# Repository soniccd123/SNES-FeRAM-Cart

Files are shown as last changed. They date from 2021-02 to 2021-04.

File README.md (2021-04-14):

# SNES FeRAM Cart
A Open Hardware SNES Cartridge with save capability

# What is that?
A repro cartridge PCB for SNES and Super Famicom consoles compatible with LoROM and HiROM software and save capability using FeRAM memory. Its a open hardware project and can be modified with no restriction

This project was possible thanks to poorstudenthobbyist (Very nice and informative guides) and whicker (Showed the basics of how to wire a FeRAM to SNES), as well as other members of NESdev forums.

# Why is that?
While there are very nice comercially available repro PCB solutions, these are closed solutions that often doesn't fit the needs of everyone, specially concerning availability of parts, so, making this project open is not only a way to give back to the community that helped me alot, but also to give the ones that need a more versitile way to solve their problems. I know that the way that this PCB was designed may not fit everyone, but i hope that the ability to modify this project as one needs solves this.

I also find the canibalization of original cartridges for making repros, while understandable in many cases, discusting, so, may this project help to curb this practice.

# Features as of now
- Suports SNES and Super Famicom
- ROM Support for up to 4MB
- HiROM and LoROM software (set by jumpers)
- 32KB of FeRAM for saving (256kb)
- No need for backup battery
- Rudimentary ROM bank switch (Permits multiple games on same ROM)
- SuperCIC support
- DOES NOT SUPPORT SPECIAL CHIP GAMES (while i would love to, this is quite away from my capacity as of now)

# Component List:
- 1x FM1808B;
- 1x 27C322 (May use other 27CXX memories with some minor modifications);
- 1x 74HC139 (or LS);
- 1x 4081;
- 1x 4071;
- 2x 74HC245;
- 1x SuperCIC (PIC12F629 model);
- 1x Led (Optional, only used for SuperCIC)
- 4x 1K Resistors (5x if using the LED with the SuperCIC);
- 1x 4 channel DIP Switch;
- 2x 10nF Capacitors;

# Technical details

This project was developed using KiCAD and can be easily modified and studied by using it. Terminals are left in the PCB for all cartridge port connections for testing, but these can easily be removed if wanted.

4081 and 4071 circuitry help to control backup RAM access and also permit FeRAM correctly reading and writing. If

While bank switching is present, its use is not absolutely required for the cart to work. In this case, the resistors are not needed, just short each SW1 channel (as if it were on). 

Also, while save capability is present, it is not required for the cart to work. 4071 and 4081 are still required in these cases

SuperCIC have been tested by other users and works. A SOIC8 footprint will be added aswell in the next commit for more package options.

# How to use

The ROMs to be written to the EPROM need to be headerless and byteswapped, this is very important. The byteswapping need is a artifact of my prototyping process and may be changed in the future.

Be sure that all chips are in the correct orientation. KiCAD stock footprint silkscreen are quite bad at indicating chip's orientation. New clearer silkscreens for the footprints may be added in the future.

ROM type: HiROM and LoROM are selected by shorting the corresponding side of all the jumpers to the center, HiROM ones are annotated with H and LoROM with L.

Bank Switching: The user may write multiple roms to the same EPROM, the DIP switch controls which area of the EPROM is read by the SNES/Super Famicom; The minimum bank size is 256KB. Each of the switches connect a memory address line between the system and the EPROM: when the switch is on, the respective address line is controlled by the SNES; When off, the EPROM adress line is pulled-up and cut from SNES control. the address lines are A20, A19, A18, A17 (considering LSB as A0). To select the desired bank, turn the switches on and off acordingly to the begining address that the ROM occupies in the EPROM.

Examples:

ROM_x begin at 0x100000 -> Switch just A19 off (pull-up);           
ROM_y begin at 0x180000 -> Switch A19 and A18 off;

This technique may not be compatible with save supporting SNES/Super Famicom software.

How to make multirom file: Just use the CMD command "copy /b rom_x.bin + rom_y.bin + rom_z.bin rom_result.bin" to join them to one file. One may join how many ROMs he wants to, just be shure that the result file is smaller than the total size of the EPROM and that the ROMs fit correctly to each desired bank to make software switching possible.

# Disclaimer

I'm not an professional engineer and created this project as a hobby, this said, problems and errors maybe present and in need to be corrected. I'll try you to help the best as I can if any problems arrise but be aware that they may exist.

Happy playing!

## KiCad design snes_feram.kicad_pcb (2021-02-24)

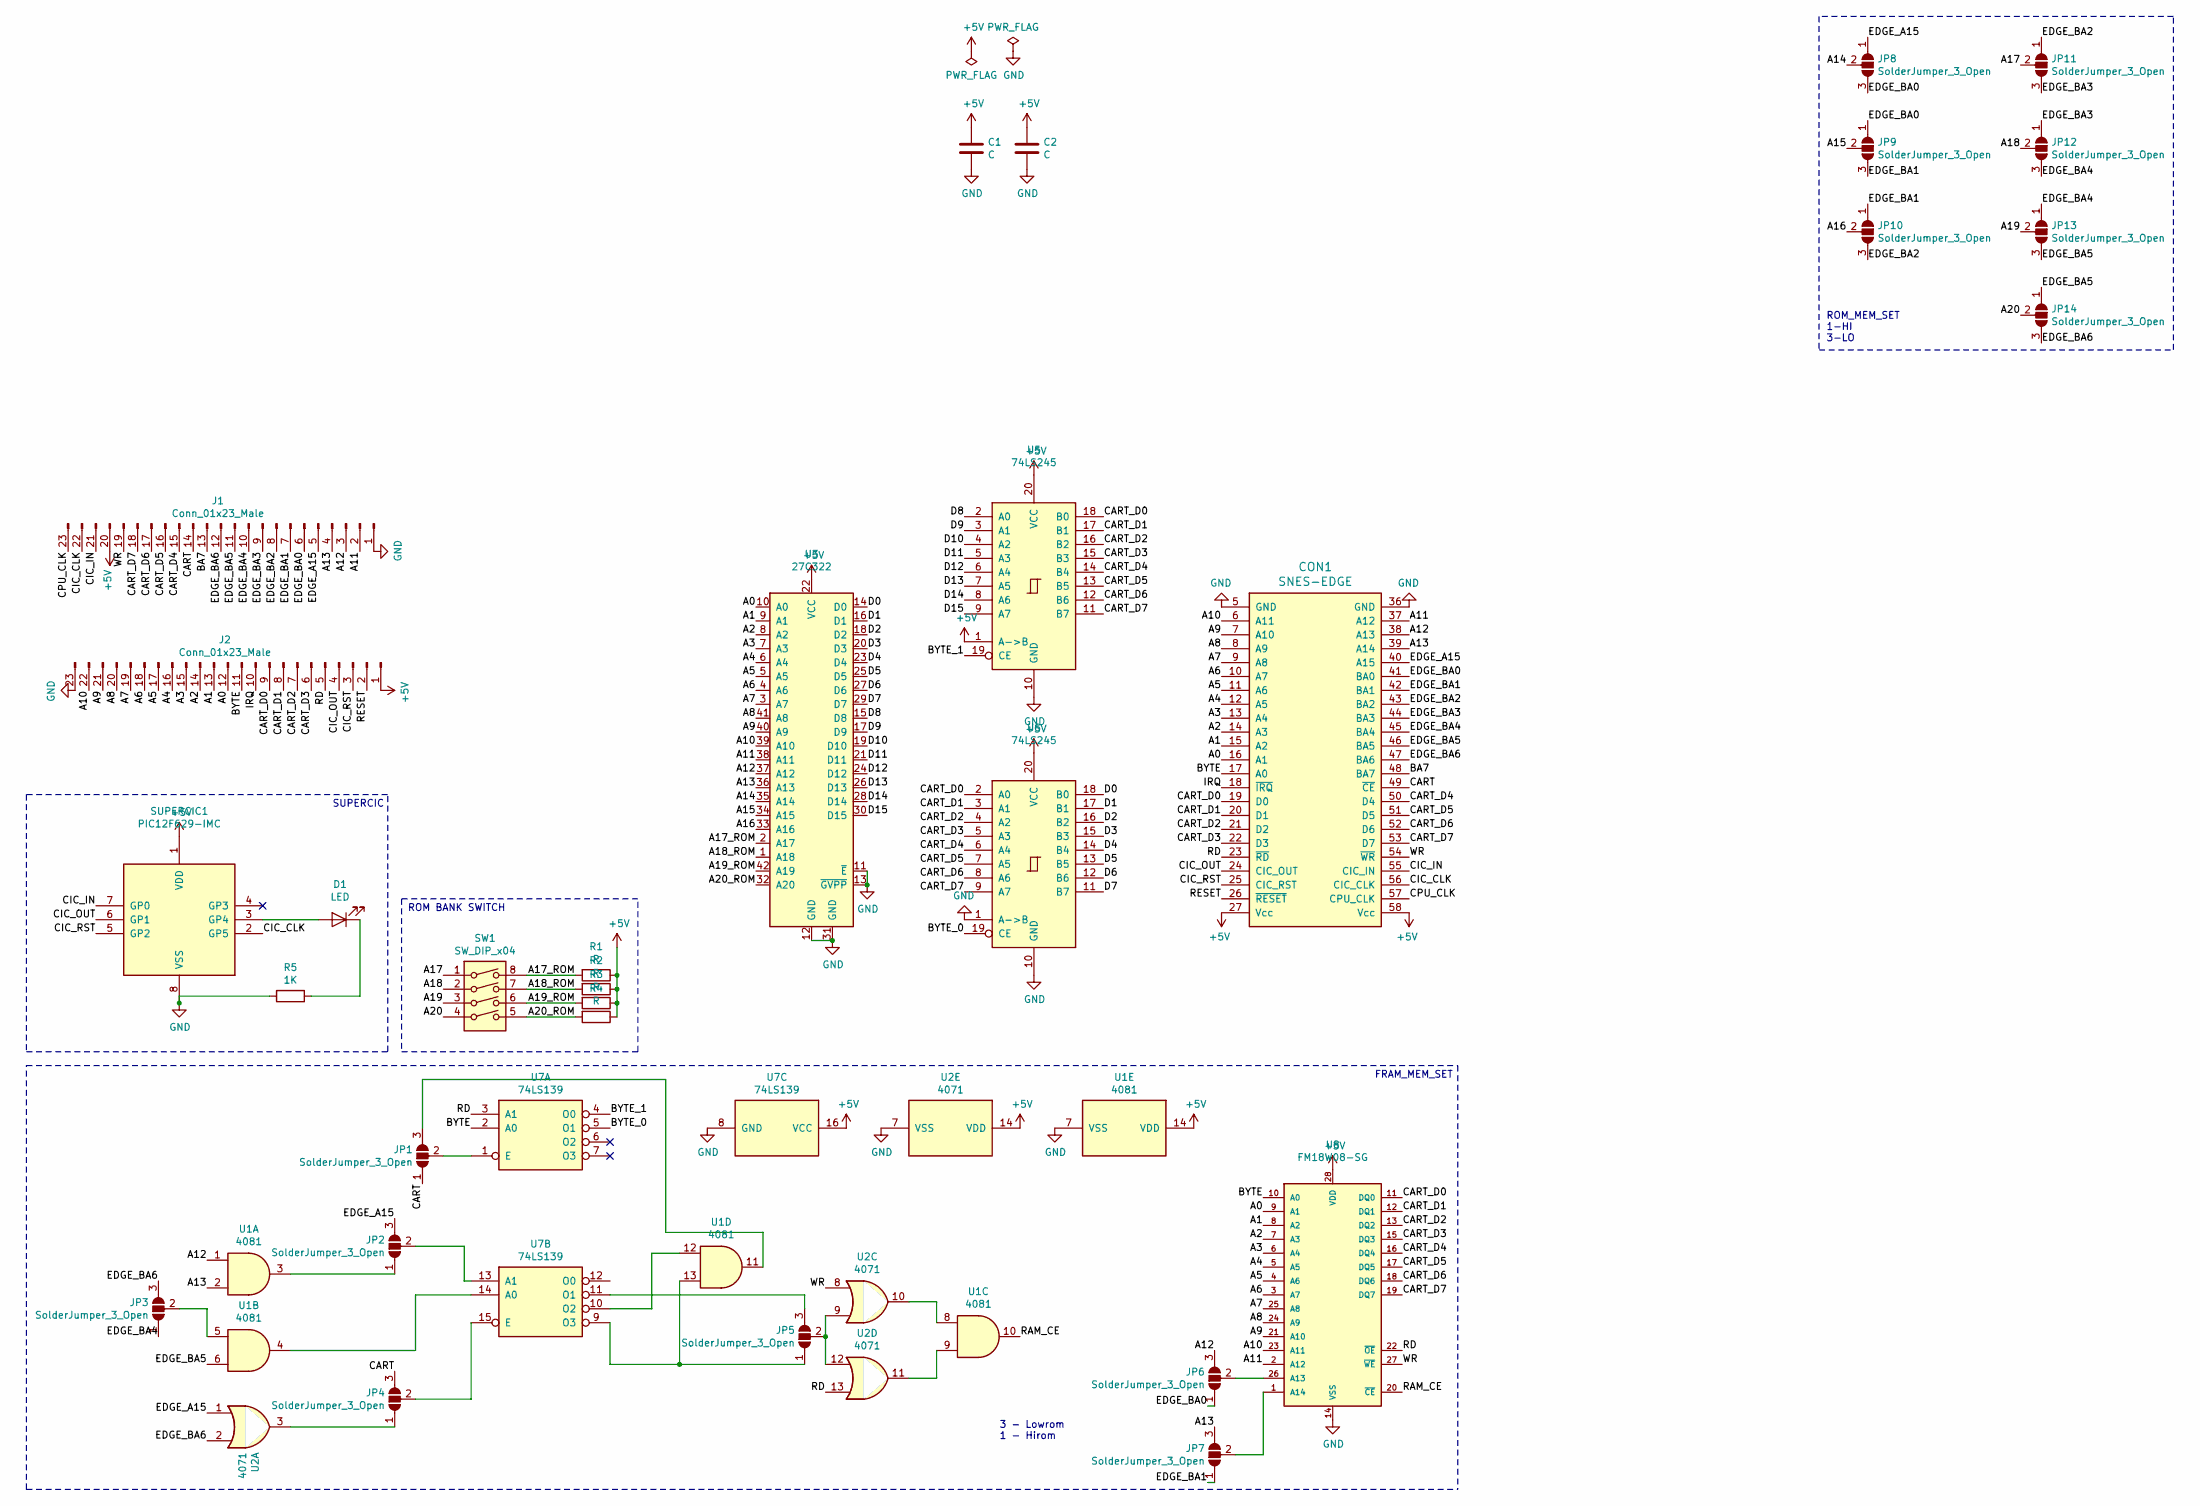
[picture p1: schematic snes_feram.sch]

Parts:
C1, C2: C; C_Disc_D5.0mm_W2.5mm_P2.50mm
CON1: SNES-EDGE; SNES-EDGE-Bigger
D1: LED; LED_D3.0mm
J1, J2: Conn_01x23_Male; PinSocket_1x23_P2.54mm_Vertical
JP1, JP2, JP3, JP4, JP5, JP6, JP7, JP8, JP9, JP10, JP11, JP12, JP13, JP14: SolderJumper_3_Open; SolderJumper-3_P1.3mm_Open_RoundedPad1.0x1.5mm
R1, R2, R3, R4: R; R_Axial_DIN0207_L6.3mm_D2.5mm_P7.62mm_Horizontal
R5: 1K; R_Axial_DIN0207_L6.3mm_D2.5mm_P7.62mm_Horizontal
SUPERCIC1: PIC12F629-IMC; DIP-8_W7.62mm
SW1: SW_DIP_x04; SW_DIP_SPSTx04_Slide_9.78x12.34mm_W7.62mm_P2.54mm
U1: 4081; SOIC-14_3.9x8.7mm_P1.27mm
U2: 4071; SOIC-14_3.9x8.7mm_P1.27mm
U3: 27C322; DIP-42_W15.24mm
U5, U6: 74LS245; SOIC-20W_7.5x12.8mm_P1.27mm
U7: 74LS139; SOIC-16_3.9x9.9mm_P1.27mm
U8: FM18W08-SG; SOIC-28W_7.5x17.9mm_P1.27mm

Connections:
+5V: C1.1, C2.1, CON1.27 (Vcc), CON1.58 (Vcc), J1.20, J2.1, R1.1, R2.1, R3.1, R4.1, SUPERCIC1.1 (VDD), U1.14 (VDD), U2.14 (VDD), U3.22 (VCC), U5.1 (A->B), U5.20 (VCC), U6.20 (VCC), U7.16 (VCC), U8.28 (VDD); also elsewhere on the board
/A0: CON1.16 (A1), J2.12, U3.10 (A0), U8.9 (A1)
/A1: CON1.15 (A2), J2.13, U3.9 (A1), U8.8 (A2)
/A2: CON1.14 (A3), J2.14, U3.8 (A2), U8.7 (A3)
/A3: CON1.13 (A4), J2.15, U3.7 (A3), U8.6 (A4)
/A4: CON1.12 (A5), J2.16, U3.6 (A4), U8.5 (A5)
/A5: CON1.11 (A6), J2.17, U3.5 (A5), U8.4 (A6)
/A6: CON1.10 (A7), J2.18, U3.4 (A6), U8.3 (A7)
/A7: CON1.9 (A8), J2.19, U3.3 (A7), U8.25 (A8)
/A8: CON1.8 (A9), J2.20, U3.41 (A8), U8.24 (A9)
/A9: CON1.7 (A10), J2.21, U3.40 (A9), U8.21 (A10)
/A10: CON1.6 (A11), J2.22, U3.39 (A10), U8.23 (A11)
/A11: CON1.37 (A12), J1.2, U3.38 (A11), U8.2 (A12)
/A12: CON1.38 (A13), J1.3, JP6.3 (B), U1.1, U3.37 (A12)
/A13: CON1.39 (A14), J1.4, JP7.3 (B), U1.2, U3.36 (A13)
/A14: JP8.2 (C), U3.35 (A14)
/A15: JP9.2 (C), U3.34 (A15)
/A16: JP10.2 (C), U3.33 (A16)
/A17: JP11.2 (C), SW1.1
/A17_ROM: R1.2, SW1.8, U3.2 (A17)
/A18: JP12.2 (C), SW1.2
/A18_ROM: R2.2, SW1.7, U3.1 (A18)
/A19: JP13.2 (C), SW1.3
/A19_ROM: R3.2, SW1.6, U3.42 (A19)
/A20: JP14.2 (C), SW1.4
/A20_ROM: R4.2, SW1.5, U3.32 (A20)
/BA7: CON1.48 (BA7), J1.13
/BYTE: CON1.17 (A0), J2.11, U7.2 (A0), U8.10 (A0)
/BYTE_0: U6.19 (CE), U7.5 (O1)
/BYTE_1: U5.19 (CE), U7.4 (O0)
/CART: CON1.49 (~CE), J1.14, JP1.1 (A), JP4.3 (B)
/CART_D0: CON1.19 (D0), J2.9, U5.18 (B0), U6.2 (A0), U8.11 (DQ0)
/CART_D1: CON1.20 (D1), J2.8, U5.17 (B1), U6.3 (A1), U8.12 (DQ1)
/CART_D2: CON1.21 (D2), J2.7, U5.16 (B2), U6.4 (A2), U8.13 (DQ2)
/CART_D3: CON1.22 (D3), J2.6, U5.15 (B3), U6.5 (A3), U8.15 (DQ3)
/CART_D4: CON1.50 (D4), J1.15, U5.14 (B4), U6.6 (A4), U8.16 (DQ4)
/CART_D5: CON1.51 (D5), J1.16, U5.13 (B5), U6.7 (A5), U8.17 (DQ5)
/CART_D6: CON1.52 (D6), J1.17, U5.12 (B6), U6.8 (A6), U8.18 (DQ6)
/CART_D7: CON1.53 (D7), J1.18, U5.11 (B7), U6.9 (A7), U8.19 (DQ7)
/CIC_CLK: CON1.56 (CIC_CLK), J1.22, SUPERCIC1.2 (GP5); also elsewhere on the board
/CIC_IN: CON1.55 (CIC_IN), J1.21, SUPERCIC1.7 (GP0); also elsewhere on the board
/CIC_OUT: CON1.24 (CIC_OUT), J2.4, SUPERCIC1.6 (GP1); also elsewhere on the board
/CIC_RST: CON1.25 (CIC_RST), J2.3, SUPERCIC1.5 (GP2); also elsewhere on the board
/CPU_CLK: CON1.57 (CPU_CLK), J1.23
/D0: U3.14 (D0), U6.18 (B0)
/D1: U3.16 (D1), U6.17 (B1)
/D2: U3.18 (D2), U6.16 (B2)
/D3: U3.20 (D3), U6.15 (B3)
/D4: U3.23 (D4), U6.14 (B4)
/D5: U3.25 (D5), U6.13 (B5)
/D6: U3.27 (D6), U6.12 (B6)
/D7: U3.29 (D7), U6.11 (B7)
/D8: U3.15 (D8), U5.2 (A0)
/D9: U3.17 (D9), U5.3 (A1)
/D10: U3.19 (D10), U5.4 (A2)
/D11: U3.21 (D11), U5.5 (A3)
/D12: U3.24 (D12), U5.6 (A4)
/D13: U3.26 (D13), U5.7 (A5)
/D14: U3.28 (D14), U5.8 (A6)
/D15: U3.30 (D15), U5.9 (A7)
/EDGE_A15: CON1.40 (A15), J1.5, JP2.3 (B), JP8.1 (A), U2.1
/EDGE_BA0: CON1.41 (BA0), J1.6, JP6.1 (A), JP8.3 (B), JP9.1 (A)
/EDGE_BA1: CON1.42 (BA1), J1.7, JP7.1 (A), JP9.3 (B), JP10.1 (A)
/EDGE_BA2: CON1.43 (BA2), J1.8, JP10.3 (B), JP11.1 (A)
/EDGE_BA3: CON1.44 (BA3), J1.9, JP11.3 (B), JP12.1 (A)
/EDGE_BA4: CON1.45 (BA4), J1.10, JP3.1 (A), JP12.3 (B), JP13.1 (A)
/EDGE_BA5: CON1.46 (BA5), J1.11, JP13.3 (B), JP14.1 (A), U1.6
/EDGE_BA6: CON1.47 (BA6), J1.12, JP3.3 (B), JP14.3 (B), U2.2
/IRQ: CON1.18 (~IRQ), J2.10
/RAM_CE: U1.10, U8.20 (~CE~)
/RD: CON1.23 (~RD), J2.5, U2.13, U7.3 (A1), U8.22 (~OE~)
/RESET: CON1.26 (~RESET), J2.2
/WR: CON1.54 (~WR), J1.19, U2.8, U8.27 (~WE~)
GND: C1.2, C2.2, CON1.5 (GND), CON1.36 (GND), J1.1, J2.23, R5.2, SUPERCIC1.8 (VSS), U1.7 (VSS), U2.7 (VSS), U3.11 (~E), U3.12 (GND), U3.13 (~GVPP), U3.31 (GND), U5.10 (GND), U6.1 (A->B), U6.10 (GND), U7.8 (GND), U8.14 (VSS); also elsewhere on the board
unnamed: D1.1 (K), R5.1
unnamed 75: D1.2 (A), SUPERCIC1.3 (GP4); also elsewhere on the board
unnamed: JP1.2 (C), U7.1 (E)
unnamed: JP1.3 (B), U1.11
unnamed: JP2.1 (A), U1.3
unnamed: JP2.2 (C), U7.13 (A1)
unnamed: JP3.2 (C), U1.5
unnamed: JP4.1 (A), U2.3
unnamed: JP4.2 (C), U7.15 (E)
unnamed: JP5.1 (A), U1.13, U7.9 (O3)
unnamed: JP5.2 (C), U2.9, U2.12
unnamed: JP5.3 (B), U7.11 (O1)
unnamed: JP6.2 (C), U8.26 (A13)
unnamed: JP7.2 (C), U8.1 (A14)
unnamed: U1.4, U7.14 (A0)
unnamed: U1.8, U2.10
unnamed: U1.9, U2.11
unnamed: U1.12, U7.10 (O2)

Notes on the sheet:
3 - Lowrom 1 - Hirom
FRAM_MEM_SET
ROM_MEM_SET 1-HI 3-LO
SUPERCIC
ROM BANK SWITCH

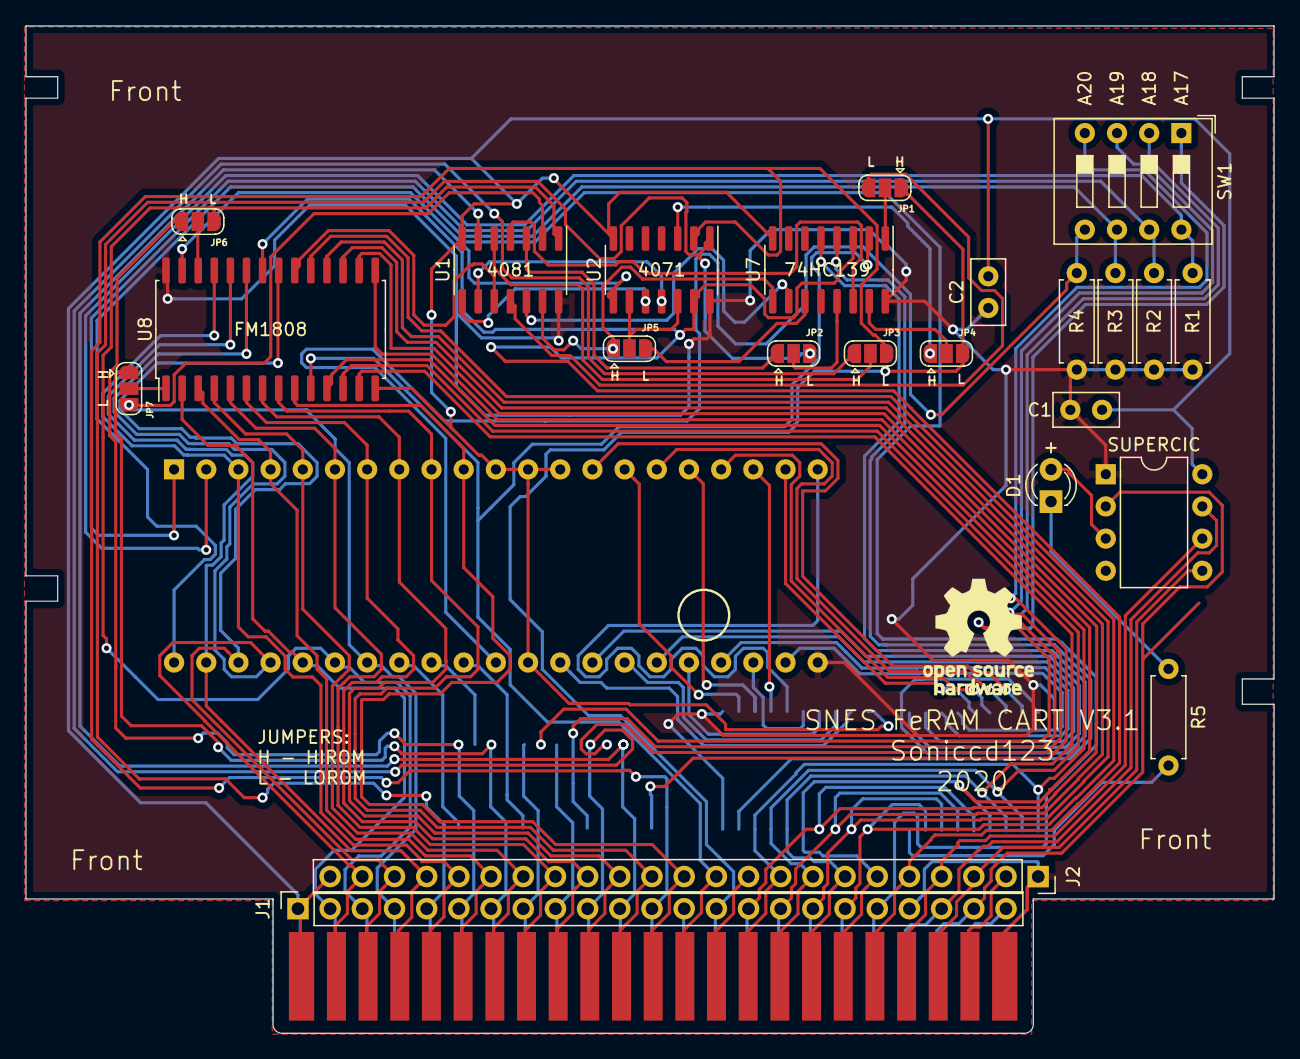
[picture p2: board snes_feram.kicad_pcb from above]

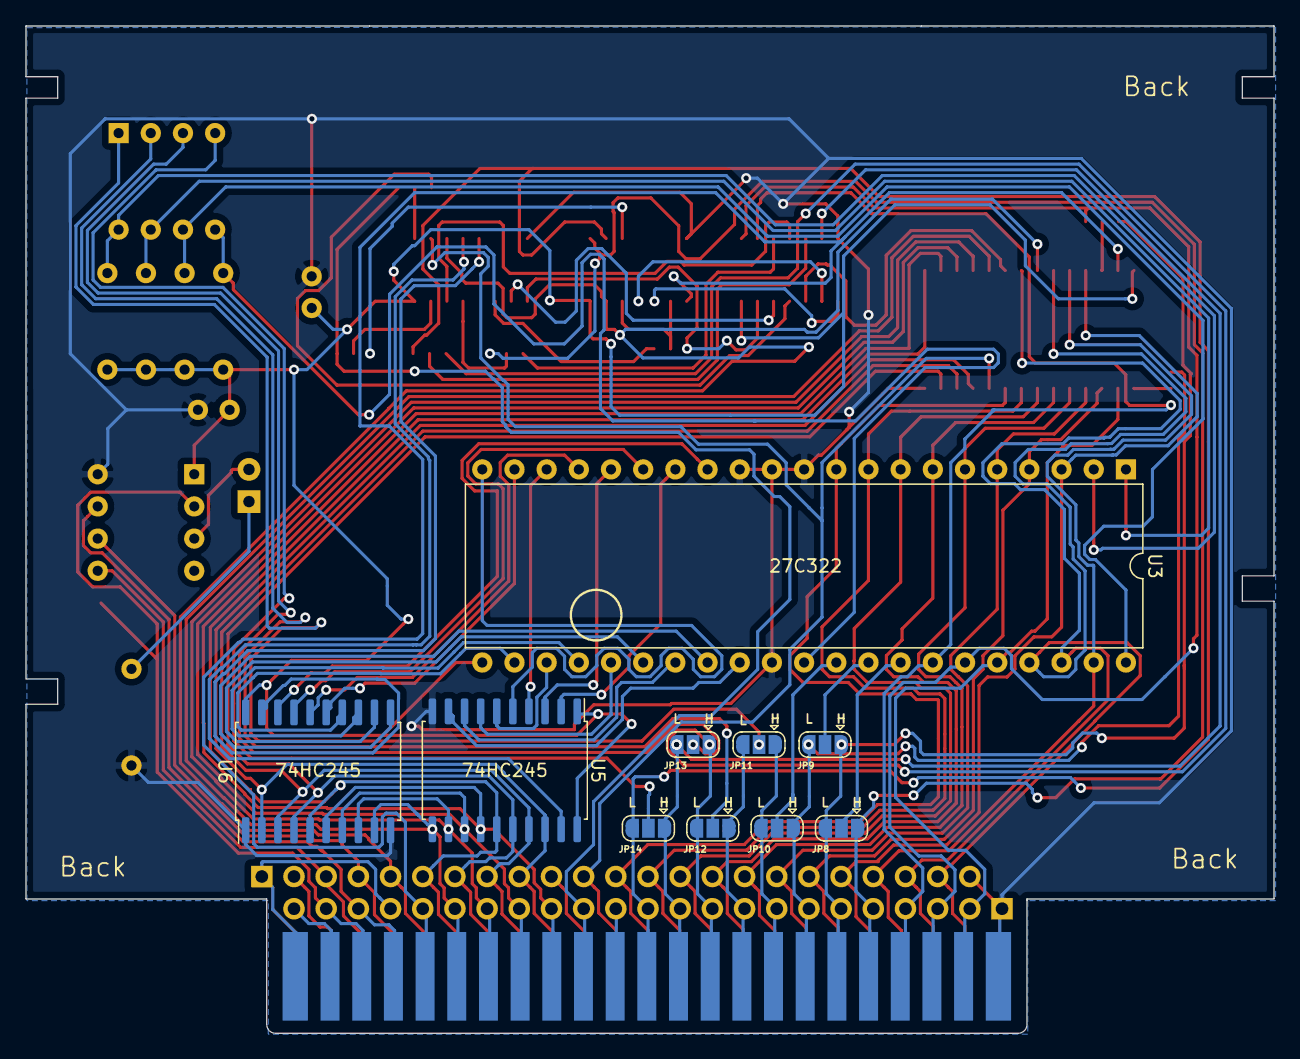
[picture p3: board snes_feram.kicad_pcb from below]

Board: 2 copper layers, 98.5 x 79.5 mm, 34 parts (10 on the bottom side), 92 nets.

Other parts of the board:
SUPERCIC: PIC12F629-IMC; DIP-8_W7.62mm

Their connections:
+5V: SUPERCIC.1; also elsewhere on the board
/CIC_CLK: SUPERCIC.2; also elsewhere on the board
/CIC_IN: SUPERCIC.7; also elsewhere on the board
/CIC_OUT: SUPERCIC.6; also elsewhere on the board
/CIC_RST: SUPERCIC.5; also elsewhere on the board
GND: SUPERCIC.8; also elsewhere on the board
unnamed 75: SUPERCIC.3; also elsewhere on the board

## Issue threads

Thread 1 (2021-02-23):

U5 has no +5V power connected to pin 20

pi1541, 2021-02-23:
Have you tried your Kicad PCB?
U5 has no +5 power connected to pin 20.
Perhaps the CMOS just works?

soniccd123, 2021-03-12:
Hey, sorry, just seen this now. It is already fixed, I forgot this trace somehow when I changed the EPROM from the front to the backside of the PCB (to fit the case correctly). Thanks for pointing out.

Closed 2021-03-12.

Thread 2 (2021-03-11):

I have made pcb in january

Pixotero, 2021-03-11:
What problems can I have? I have pcb model january but if the pin 20 is wrong, can I solution this problem? Is a important problem? Sorry for my english, I hope you understand my cuestion. Thanks

soniccd123, 2021-03-12:
Hey, it was my fault, I forgot to connect the pin 20 when I made some changes, but it is very easy to fix, just connect pin 20 to 5v using a small jumper wire (U5 pin 1 is a good candidate). It is already fixed since last commit, but for those who had built PCBs before, this should fix it. The cart will probably not work if this is not done.

When you build your PCB, just confirm to me that it works so I can close the Issue :)

Pixotero, 2021-03-15:
I have built PCB before, I am going apply the solution that you have to proposed to me. anyway, I am studying how to make the cartridges because I am a beginner. I have the list of components and the pcb, but I need to know which ones to use and how, I know that I need to program 27c322 and pic12f629, but I don't know which components to solder. Thanks for your solution. I will write my progress if you want, thanks again

Pixotero, 2022-10-29:
I have abandoned the project for months because I have not been able to program 27c322 with the willem programmer. I would like to resume it, I don't know if you could help me with that, thanks

soniccd123, 2022-10-29:
Hi friend, unfortunately, I program my EPROMs with a custom programmer that I built, but any programmer capable of writting 27c322 should work. I don't know how can I help you with that

alexwinger, 2023-09-17:
I built a pcb the cart is working without any modification. So i think you can close the issue

SiscuPrats, 2024-01-09:
I would like to know if in the end the project and the board works correctly. Has anyone finally tested the prototype and programmed any game?

alexwinger, 2024-03-11:
> I would like to know if in the end the project and the board works correctly. Has anyone finally tested the prototype and programmed any game?

It worked for me, but you have to swap the bytes before flashing (Odd <==> Even)

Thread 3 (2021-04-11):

Does this design work?

pi1541, 2021-04-11:
Hi.
I have made a number of these but I can't get any of them to work.
I am trying V3.1.
I am trying many HiROM images and have all the jumpers set to H.
I have all the dip switches turned on.

I have a wire jumper from pin 1 to pin 20 of U5 to fix the missing 5v connection to pin 20 of U5. Is this correct?
Can I confirm that the silk screen for U1, U2 and U7 is the wrong way around and all of these chips have their pin 1 closest to the left side of the board where the dip switches are? That is opposite to the U labels on the silk screen.
Are any other markings on the silk screen wrong?

When you say "byte swapped" do you mean byte swapped using a tool like Wasabi or do you mean 16bit endian byte swapped? I have tried both and neither worked.

I know that my CIC chip works as it works successfully in other designs.

I don't know what to try next. All attempt give a black screen.

I have built other peoples designs without issue but can't seem get this one to work.
Any help or advice would be greatly appreciated.
I want to use this design as it has many desirable features and looks like it is the best one yet.

Oh, and another little thing. In the README.dm in the paragraph about bank switching it talks about the Sega Genesis and not the SNES.

Thanks.

soniccd123, 2021-04-14:
Hello!

Yes, the design work, me and a bunch of other users at NesDev forums have tested it and made repros successfully.

The wire from pin 1 to 20 on U5 is correct and works. Also, I can confirm that U1, U2 and U7 have indeed pin 1 in direction of the DIP switches. Thanks for pointing out, may change the silkscreen in next commit.

Be aware that U5 and U6 are both in oposite directions from each other, in this case, U5 pin 1 is in direction of the back side jumpers.

To see the correct orientation of the chips in KiCAD, take a look at the F.Fab and B.Fab layers, they show the pin 1 of each chip explicitly. KiCAD's silkscreen markings are terrible, in the next commit, I will add very explicit marks for pin 1 of each chip, as this is causing problems even to me lol.

With byteswapped I mean that odd and even bytes must be swapped, if bytes 0, 1, 2 and 3 in the file are A, B, C and D you must write them in the EPROM as B, A, D, C. Each word must be swapped, so it is 16bit endianness, not the Wasabi swap (that changes addresses to fit diferent EPROMs pinouts).

Thanks for pointing out about the Genesis mistake, I use the exact same bank switching method in this and my Genesis Repro, so must have forgot to change the names lol.

Hope this helps!

pi1541, 2021-04-16:
Thanks, I will keep debugging my soldering work.

pi1541, 2021-06-13:
I tried it on another SNES and it worked perfectly. Thanks.

Closed 2021-06-13.

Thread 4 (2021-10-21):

FM16W08-SG (64Kbit)

StanMOI, 2021-10-21:
Hi sonnic,

I would like to use **FM16W08-SG** (64Kbit).
I see that only **pin 1** and **pin 26** are not used with FM16W08.
Should I do something else with FM16W08 when its for Hirom or Lorom use?
Will adress pins changes for **FM16W08-SG** if I will use it for Hirom or Lorom game? (Like in the case of FM18W08).
Or all I need to do Is just tied all pins to respective address names, except pin 1 and 26 (that need to be tied to GND).
Thank you for help.
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

soniccd123, 2021-11-01:
Hi friend, from what I remember you can just solder the FM1608 directly in the FM1808 footprint without modifications, the are pin compatible. Also, I may be wrong, but I think you won't need the connect the NC pins to GND...

The HiROM and LoROM connection schemes access the cartridge in diferently sized banks (32kbit and 64kbit), they also have the save memory mapped in diferent locations in the SNES address space, thats why they're wired diferently.

May I ask why are you interested in using diferent sized FeRAMs like 16kbit? If it is because of the anti-copier/flashcart checks that some games like DKC2 do, you can just crack these games before writing the EEPROM with UCON64 and use bigger save memory sizes

StanMOI, 2021-11-01:
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

Hi sonnic,
Thank you for your answer.
Yes,
I know that some games that DLC2 do check anti-copier/flashcart and it’s can be cracked with UCON64,
 but I still would like to have that option on my future PCB that you can to choose what feram size i will solder on it (like fm1608 with 64Kbit…) etc.
Why not?
And maybe also, just to avoid to use ucon64 or other applications when it can be avoided.
:)

soniccd123, 2022-01-24:
Hello friend,

I'm sorry that it to took so long to reply, the last semester was quite hard at college and i didn't had the time to look into my project for the last few months. Hopefully i'll get more time this year.

Well, using the correct sized FeRAM is perfectly possible, just solder it as shown in the chip pinout and it should work, the higher addresses will simply not be connected. Yet I must warn you that I have not tested this, if you try it, please be sure to report any trouble or success here, it will be very much apreciated! I won't test because while I have quite a large collection of FM1808 chips laying arround, I don't have any FM16W08 to test it. About the NC to GND situation, I'm not sure, it really depends if the pins are really internally connected to the silicon, I can't really answer that about the FM16W08

About the mapping, it does not depend on the game size, HiROM and LoROM will map the save to their respective address in the address space. Size can influence the complexity of the save RAM mappers, as smaller games tends to not try to read higher addresses that may conflict with the save RAM.

We can keep the same pins for the FeRAM footprint because as the jumpers are shorted for LoROM or HiROM in my board, the important pins that maps the save RAM for each one are changed. Thats why this project PCB has so much jumpers.

When I was designing this project, The main resource I used for understanding the memory mapping was poorstudenthobbys blog (today know as Mouse Bite Labs), It has a lot of information explaining how to mapping words. Also, the NESdev forums had a lot of resources, unfortunately, it seems to be offline, I hope that it comes back one day or, at least, a backup of it remains

Don't be sorry! I'm glad that you're interested in the project, I hope to have helped with your questions. If you have anymore questions or need more indepth answers, don't be afraid to ask!

StanMOI, 2022-02-01:
Thank you for answer soniccd123.

I have some more questions for you.

- 74LS245 (Octal Bus Transceiver): For what function do you use it on your board?
Others board using "multiplexers" like 74*257 to convert data from EPROM (16bit) to SNES system (8bit).
I see that you don't have any Multiplexer. Why?

- I see on your schema "**BYTE_0**" and "**BYTE_1**" between decoder 74LS139 (pins 4 and 5) and 74LS245 (pin19 CE)
and also  "**BYTE**" between SNES-EDGE pin17 (A0) and FM18W08 pin10 (A0).
Why?
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

- I would like to try your schema for using with Flash chip like MX29LV320 (8 bit) instead of EPROM 32MBIT (16bit).
If I setup Flash chip to 8bit, so I don't need any multiplexer.
With Flash chip, do I still have to use  2x 74LS245 ?
Do i have to keep all pinouts with name "BYTE" (BYTE, BYTE_0, BYTE_1).
Do you think it can works?
Or schema have to be changed for flash chip?
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

And just to let you know, NESdev forum work again ;)

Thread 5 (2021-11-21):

Problem on the SRAM enable logic of the 4081-U1B part

SONIC3D, 2021-11-21:
Thanks for your nice project. I'm reading your schematic yesterday, with an SNES cart mapping doc on "[http://gatchan.net/uploads/Consoles/SNES/Flashcard/SNES_MemMap.txt](http://gatchan.net/uploads/Consoles/SNES/Flashcard/SNES_MemMap.txt)"
and "[https://wiki.superfamicom.org/schematics-ports-and-pinouts](https://wiki.superfamicom.org/schematics-ports-and-pinouts)"

I found the SRAM mapping is different from what the doc described. So I create this issue to request your help on confirming if it's intended or just small fault on drawing schematic.

(All address pin name below is referencing to CartSlot pin name, not the NET name in your KiCAD project.)

### HiROM mode

With this doc the SRAM enable logic equation in "HiROM mode" is:

```
!SRAM_CE = (!A15 & BA5 & A14 & A13) & (!nCART & nRESET)
or
!SRAM_CE = (!BA6 & BA5 & A14 & A13) & (!nCART & nRESET)
```
and the SRAM should be mapped to segment $20-$3F and $A0-$BF.

When JP1-JP5 shorted with pin1-pin2.(Enable HiROM mode)
Focusing on the part (!A15 & BA5 & A14 & A13) or (!BA6 & BA5 & A14 & A13):
* 4071-U2A part is corresponding to (!A15 and !BA6) which is OK for general adaption.
* 4081-U1A part is corresponding to (A14 & A13).
* But for 4081-U1B part, the equation in your schematic is (BA4 & BA5). Which contains an additional BA4.
This makes the SRAM be mapped to segment $30-$3F and $B0-$BF. Which is different from the known doc.

### LoROM mode

With this doc the SRAM enable logic equation in "LoROM mode" is:
```
!SRAM_CE = (Vcc & BA5 & BA4 & !A15) & (!nCART & nRESET)
or
!SRAM_CE = (BA6 & BA5 & BA4 & !A15) & (!nCART & nRESET)
```
and the SRAM should be mapped to segment $70-$7D and $F0-$FF.

When JP1-JP5 shorted with pin3-pin2.(Enable LoROM mode)
Focusing on the part (Vcc & BA5 & BA4 & !A15) or (BA6 & BA5 & BA4 & !A15):
* JP4 connected to /CART filtered segment $7E-$7F. That's ok.
* 4081-U1A part is corresponding to (!A15). That's ok.
* But for 4081-U1B part the equation in your schematic is (BA6 & BA5). So the BA4 is missed in expression.
This makes the SRAM be mapped to segment $60-$7D and $E0-$FF. Which is different from the known doc.

### My modification
If the above problem is indeed mistake in drawing. I think the modification can be like below.

The solution A uses the expression (BA6 & BA5 & BA4 & !A15) in LoROM mode. It requires an additional AND gate. So I added an 4081. Or it can be achieved with an 3-input AND gate with BA4 BA5 BA6 as input.
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

The solution A uses the expression (Vcc & BA5 & BA4 & !A15), so the Vcc can be skipped in AND. The additional AND gate component can be saved. The jumper can also be moved to right of the 4081, thus the +5V Vcc can be skipped for HiROM mode.
(Note: I'm still not clear if (Vcc & BA5 & BA4 & !A15) can be apply to all game, as I think this constraint is more wide than adding BA6. I'm not sure if it will interfere other logic in the corresponding page. I'm not that familiar with SNES.)

SONIC3D, 2021-11-21:
And pin1 of JP1 currently connects the /CART.
So in HiROM mode(JP1-JP14 all connect pin1-pin2). The ROM data bus will always output on /RD, even on SRAM address range like $3F:$6000. It should interfere the SRAM output.

I think the pin1 of JP1 should connect to logic output of:
```
(!nCART and BA6) or (!nCART and !BA6 and A15)
=
!nCART and (BA6 or (!BA6 and A15))
```
2 AND gates and 1 OR gate.

So that the following mapping is achieved:
```
	SNES 00:8000-FFFF <---	ROM 008000-00FFFF     // 0000-7FFF is not mapped. Only 8000-FFFF.  (!BA6 and A15)
	SNES 01:8000-FFFF <---	ROM 018000-01FFFF      // Similar, 10000-17FFF is not mapped
	SNES 02:8000-FFFF <---	ROM 028000-02FFFF
	SNES 03:8000-FFFF <---	ROM 038000-03FFFF
	...
	SNES 3E:8000-FFFF <---	ROM 3E8000-3EFFFF
	SNES 3F:8000-FFFF <---	ROM 3F8000-3FFFFF

	SNES 40:0000-FFFF <---	ROM 000000-00FFFF    // 0000-FFFF are all mapped. (BA6)
	SNES 41:0000-FFFF <---	ROM 010000-01FFFF
	SNES 42:0000-FFFF <---	ROM 020000-02FFFF
	SNES 43:0000-FFFF <---	ROM 030000-03FFFF
	... etc

	SNES 7E:0000-FFFF <---	System RAM                    // Here /Cart is high
	SNES 7F:0000-FFFF <---	System RAM                    // Here /Cart is high

	//same thing in banks 80-FF
	//except FE-FF holds more ROM instead of System RAM

	SNES 80:8000-FFFF <---	ROM 008000-00FFFF     // 0000-7FFF is not mapped
	SNES 81:8000-FFFF <---	ROM 018000-01FFFF      // Similar, 10000-17FFF is not mapped
	SNES 82:8000-FFFF <---	ROM 028000-02FFFF
	SNES 83:8000-FFFF <---	ROM 038000-03FFFF
	...
	SNES BE:8000-FFFF <---	ROM 3E8000-3EFFFF
	SNES BF:8000-FFFF <---	ROM 3F8000-3FFFFF

	SNES C0:0000-FFFF <---	ROM 000000-00FFFF
	SNES C1:0000-FFFF <---	ROM 010000-01FFFF
	SNES C2:0000-FFFF <---	ROM 020000-02FFFF
	SNES C3:0000-FFFF <---	ROM 030000-03FFFF
	... etc

	SNES FE:0000-FFFF <---	ROM 3E0000-3EFFFF
	SNES FF:0000-FFFF <---	ROM 3F0000-3FFFFF
```

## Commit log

2020-10-26 Parts annotated
    [snes_feram.kicad_pcb]
2020-10-26 Forgot to add protection resistor to LED
    [snes_feram.kicad_pcb, snes_feram.sch]
2020-10-26 Updated Gerber files
    [snes_feram-B_Cu.gbr, snes_feram-B_Mask.gbr, snes_feram-B_Paste.gbr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]
2020-11-02 EPROM is now on the back of PCB for better shell fit; Silkscreen mark for shell contact points corrected
    [snes_feram.kicad_pcb]
2020-11-02 Small change on silkscreen
    [snes_feram.kicad_pcb]
2020-11-02 Gerber updated with last changes
    [snes_feram-B_Cu.gbr, snes_feram-B_Mask.gbr, snes_feram-B_Paste.gbr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]
2021-02-24 Corrected missing trace at pin 20 of U5, thanks to @DeLFuS
    [snes_feram-B_Cu.gbr, snes_feram-B_Mask.gbr, snes_feram-B_Paste.gbr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]
